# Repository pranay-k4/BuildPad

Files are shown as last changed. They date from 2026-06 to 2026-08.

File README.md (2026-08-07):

# BuildPad
BuildPad is customizable macro pad with OLED display, layers, media controls and more.

## Why BuildPad?
BuildPad is customizable open-source macropad for makers, coders, designers, and electronics builders and why I made this because building something yourself is way more fun than buying it and I love hardware.

## Features
- 6 programmable mechanical keys
- Rotary encoder
- OLED display
- RGB lighting
- Custom firmware
- Open-source hardware
- Bongo Cat animation

## CAD Render
Opera Snapshot_2026-07-03_222907_cad onshape com
Opera Snapshot_2026-07-03_222953_cad onshape com

## PCB Screenshots



## Hardware
- XIAO RP2040
- SSD1306 128×32 OLED
- MX Cherry Switches
- SK6812 MINI E Leds
- EC11 Rotary Encoder

## Build Your Own BuildPad

### 1. Order the PCB
Export the Gerber files from the PCB folder and order the board from your preferred PCB manufacturer.

### 2. Print the Case
Print the top and bottom case parts using the files in the case directory.

[CAD Source](https://cad.onshape.com/documents/56e50c354be83b1f527c4f36/w/ea902eb5d511072ea0b73db3/e/02ae305e326d8373da2c26ce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)

### 3. Gather Components
Use the BOM to source all required components.

### 4. Assemble the PCB
Solder:
1. Diodes
2. RGB LEDs
3. XIAO RP2040
4. OLED Display
5. Rotary Encoder
6. Mechanical Switches

### 5. Install Heat Set Inserts
Install M2 heat-set inserts into the top case.

### 6. Flash Firmware
Install QMK and compile:
```bash
qmk compile -kb buildpad -km default
```
Flash the generated firmware onto the XIAO RP2040.

### 7. Assemble the Case
Mount the PCB inside the case and secure everything using M2 screws.

## BOM
# Bill of Materials

| Item | Qty | Component | Specification | Price | Link |
|---|-----|---|---|---|---|
| 1 | 1 | Microcontroller | Seeed Studio XIAO RP2040 | ~$6-7 | https://robu.in/product/seeed-studio-xiao-rp2040-v1-0/ |
| 2 | 1 | OLED Display | 0.91in SSD1306 I2C OLED (128x32) | ~$2.5 | https://robu.in/product/0-91-inch-128x32-i2c-iic-serial-blue-oled-lcd-display-module/ |
| 3 | 1 | Rotary Encoder | EC11 Encoder with Push Switch | ~$0.6 | https://robu.in/product/hongyan-ec11h-7ce20p1zy20-rotary-encoder-with-push-button-switch-vertical-plug-in-5-pin/ |
| 4 | 1 | Mechanical Switches | Cherry MX Compatible Switches (Pack of 10) | ~$4 | https://meckeys.com/shop/accessories/keyboard-accessories/key-switches/cherry-mx-rgb-switch/ |
| 5 | 2 | Keycaps | MX Compatible Keycaps (Pack of 5) | ~$2 | https://meckeys.com/shop/accessories/keyboard-accessories/keycaps/blank/blank-dsa-keycaps-1u/ |
| 6 | 8 | RGB LEDs | SK6812MINI-E Reverse Mount RGB LEDs | ~$3 | https://www.lcsc.com/product-detail/C5149201.html |
| 7 | 6 | Diodes | 1N4148W SOD-123 | ~$0.5 | https://www.lcsc.com/product-detail/C81598.html |
| 8 | 1 | PCB | BuildPad v1 PCB | $4 + $8 shipping | JLCPCB |
| 9 | 1 | Case | BuildPad v1 3D Printed Case | - | - |
| 10 | 8 | Heat Set Inserts | M2 Brass Heat Set Inserts | ~$1.5 | https://robu.in/product/m2-x-4-mm-brass-insert/ |
| 11 | 4 | Screws | M2 Machine Screws 12mm Long | ~$0.5 | https://robu.in/product/easymech-m2-x-12mm-hex-allen-csk-high-tensile109-black-oxide-screw-dia-2mm-length-12mm/ |
| 12 | 4 | Screws | M2 Machine Screws 4mm Long | ~$0.5 | TBD |
| 13 | 1 | Encoder Knob | 6mm Shaft Encoder Knob | ~$1 | TBD |

## License
This project is licensed under the MIT License.

## Author
Pranay Kamle

BuildPad v1 • 2026

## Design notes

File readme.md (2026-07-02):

# buildpad

buildpad

*A short description of the keyboard/project*

* Keyboard Maintainer: [Pranay](https://https://github.com/pranay-k4)
* Hardware Supported: *The PCBs, controllers supported*
* Hardware Availability: *Links to where you can find this hardware*

Make example for this keyboard (after setting up your build environment):

    make buildpad:default

Flashing example for this keyboard:

    make buildpad:default:flash

See the [build environment setup](https://docs.qmk.fm/#/getting_started_build_tools) and the [make instructions](https://docs.qmk.fm/#/getting_started_make_guide) for more information. Brand new to QMK? Start with our [Complete Newbs Guide](https://docs.qmk.fm/#/newbs).

## Bootloader

Enter the bootloader in 3 ways:

* **Bootmagic reset**: Hold down the key at (0,0) in the matrix (usually the top left key or Escape) and plug in the keyboard
* **Physical reset button**: Briefly press the button on the back of the PCB - some may have pads you must short instead
* **Keycode in layout**: Press the key mapped to `QK_BOOT` if it is available

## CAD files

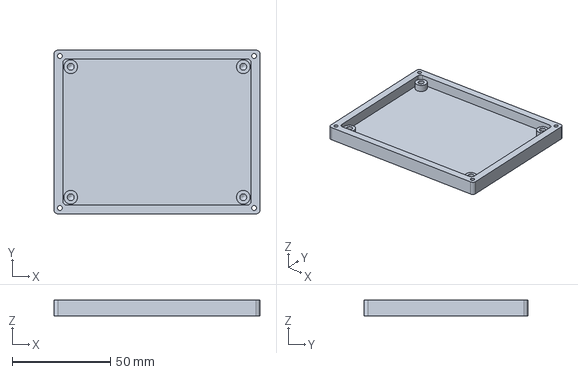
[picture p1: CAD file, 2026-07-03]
cad/Bottom part.step
105.0 x 83.5 x 8.00 mm

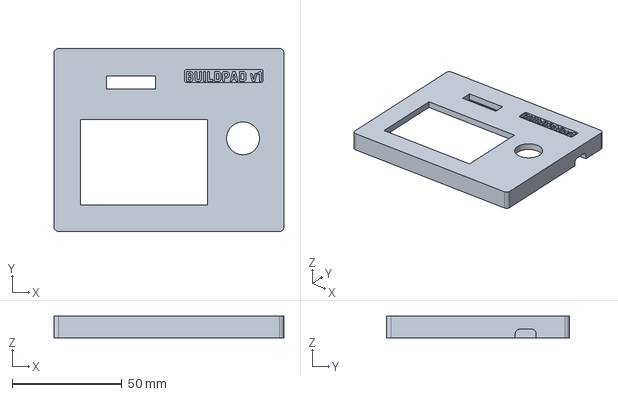
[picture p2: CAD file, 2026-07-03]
cad/Top part.step
105.0 x 83.5 x 10.0 mm

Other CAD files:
cad/Assembly.step
cad/Top part (1).stl
cad/Bottom part (1).stl
cad/Bottom part.stl
cad/Top part.stl

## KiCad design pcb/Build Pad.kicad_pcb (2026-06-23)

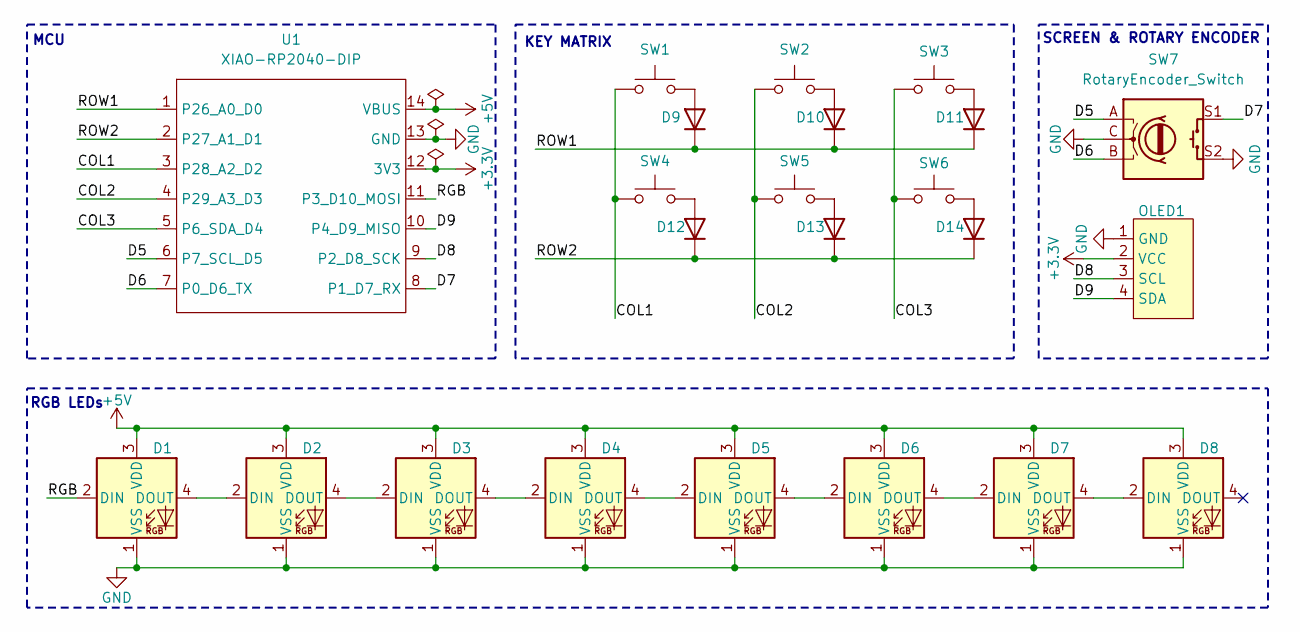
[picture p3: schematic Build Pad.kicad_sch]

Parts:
D1, D2, D3, D4, D5, D6, D7, D8: SK6812MINI-E; LED_SK6812MINI-E_3.2x2.8mm_P1.5mm_ReverseMount
D9, D10, D11, D12, D13, D14: 1N4148; D_SOD-123
OLED1: HS91L02W2C01; OLED-TH_L38.0-W12.0_HS91L02W2C01; MPN HS91L02W2C01; LCSC Part C5248081
SW1, SW2, SW3, SW4, SW5, SW6: SW_Push; SW_Cherry_MX_1.00u_PCB
SW7: RotaryEncoder_Switch; RotaryEncoder_Alps_EC11E-Switch_Vertical_H20mm_CircularMoun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
U1: XIAO-RP2040-DIP

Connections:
+3.3V: OLED1.2 (VCC), U1.12 (3V3)
+5V: D1.3 (VDD), D2.3 (VDD), D3.3 (VDD), D4.3 (VDD), D5.3 (VDD), D6.3 (VDD), D7.3 (VDD), D8.3 (VDD), U1.14 (VBUS)
/COL1: SW1.1, SW4.1, U1.3 (P28_A2_D2)
/COL2: SW2.1, SW5.1, U1.4 (P29_A3_D3)
/COL3: SW3.1, SW6.1, U1.5 (P6_SDA_D4)
/D5: SW7.A, U1.6 (P7_SCL_D5)
/D6: SW7.B, U1.7 (P0_D6_TX)
/D7: SW7.S1, U1.8 (P1_D7_RX)
/D8: OLED1.3 (SCL), U1.9 (P2_D8_SCK)
/D9: OLED1.4 (SDA), U1.10 (P4_D9_MISO)
/RGB: D1.2 (DIN), U1.11 (P3_D10_MOSI)
/ROW1: D9.1 (K), D10.1 (K), D11.1 (K), U1.1 (P26_A0_D0)
/ROW2: D12.1 (K), D13.1 (K), D14.1 (K), U1.2 (P27_A1_D1)
GND: D1.1 (VSS), D2.1 (VSS), D3.1 (VSS), D4.1 (VSS), D5.1 (VSS), D6.1 (VSS), D7.1 (VSS), D8.1 (VSS), OLED1.1 (GND), SW7.C, SW7.S2, U1.13 (GND)
unnamed: D1.4 (DOUT), D2.2 (DIN)
unnamed: D2.4 (DOUT), D3.2 (DIN)
unnamed: D3.4 (DOUT), D4.2 (DIN)
unnamed: D4.4 (DOUT), D5.2 (DIN)
unnamed: D5.4 (DOUT), D6.2 (DIN)
unnamed: D6.4 (DOUT), D7.2 (DIN)
unnamed: D7.4 (DOUT), D8.2 (DIN)
unnamed: D9.2 (A), SW1.2
unnamed: D10.2 (A), SW2.2
unnamed: D11.2 (A), SW3.2
unnamed: D12.2 (A), SW4.2
unnamed: D13.2 (A), SW5.2
unnamed: D14.2 (A), SW6.2

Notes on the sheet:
MCU
RGB LEDs
SCREEN & ROTARY ENCODER
KEY MATRIX

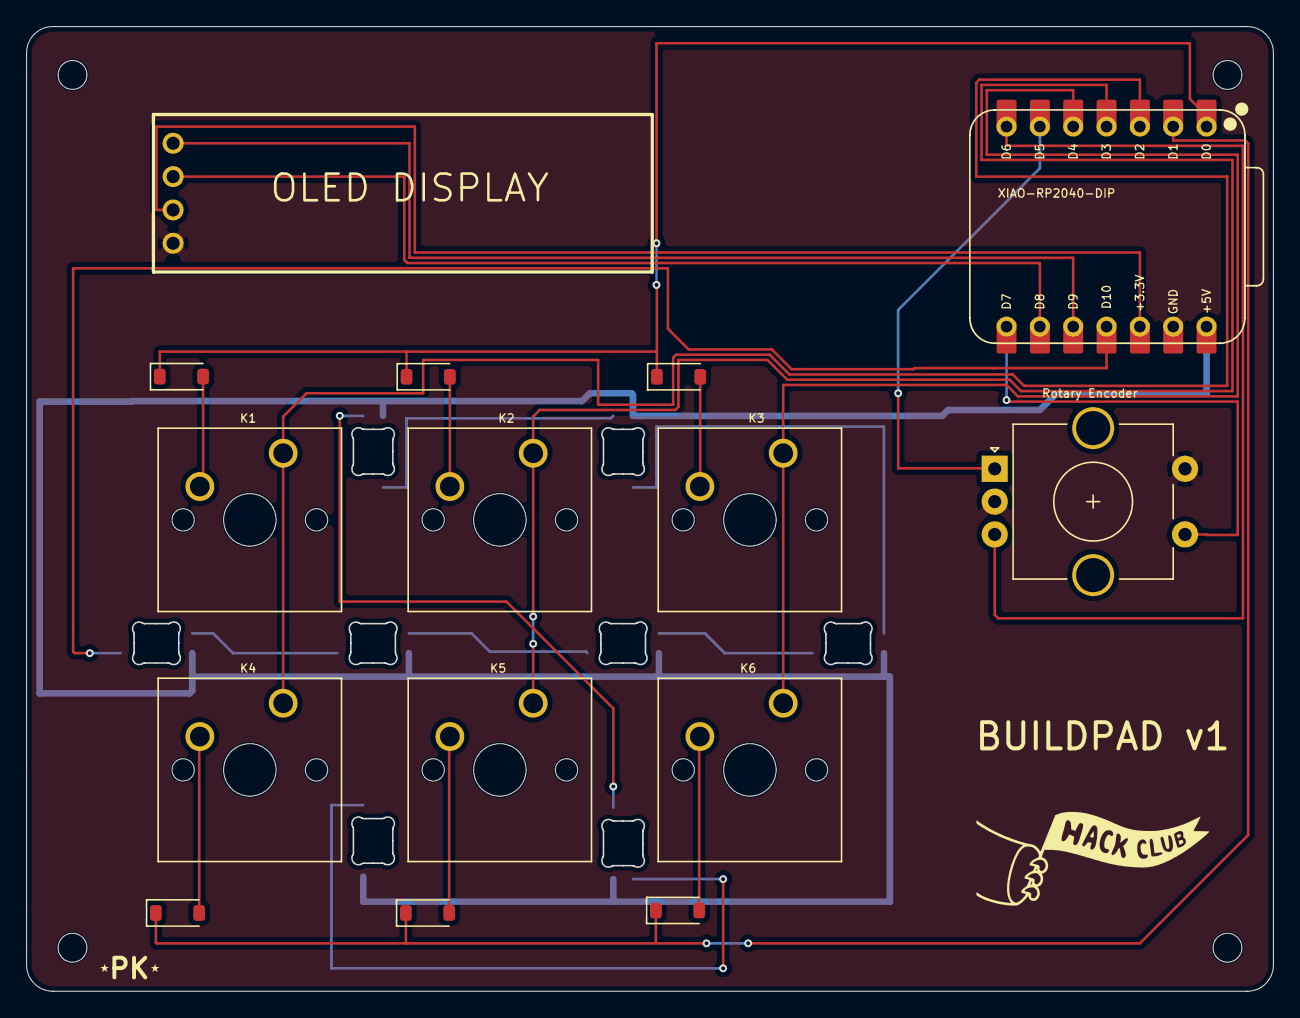
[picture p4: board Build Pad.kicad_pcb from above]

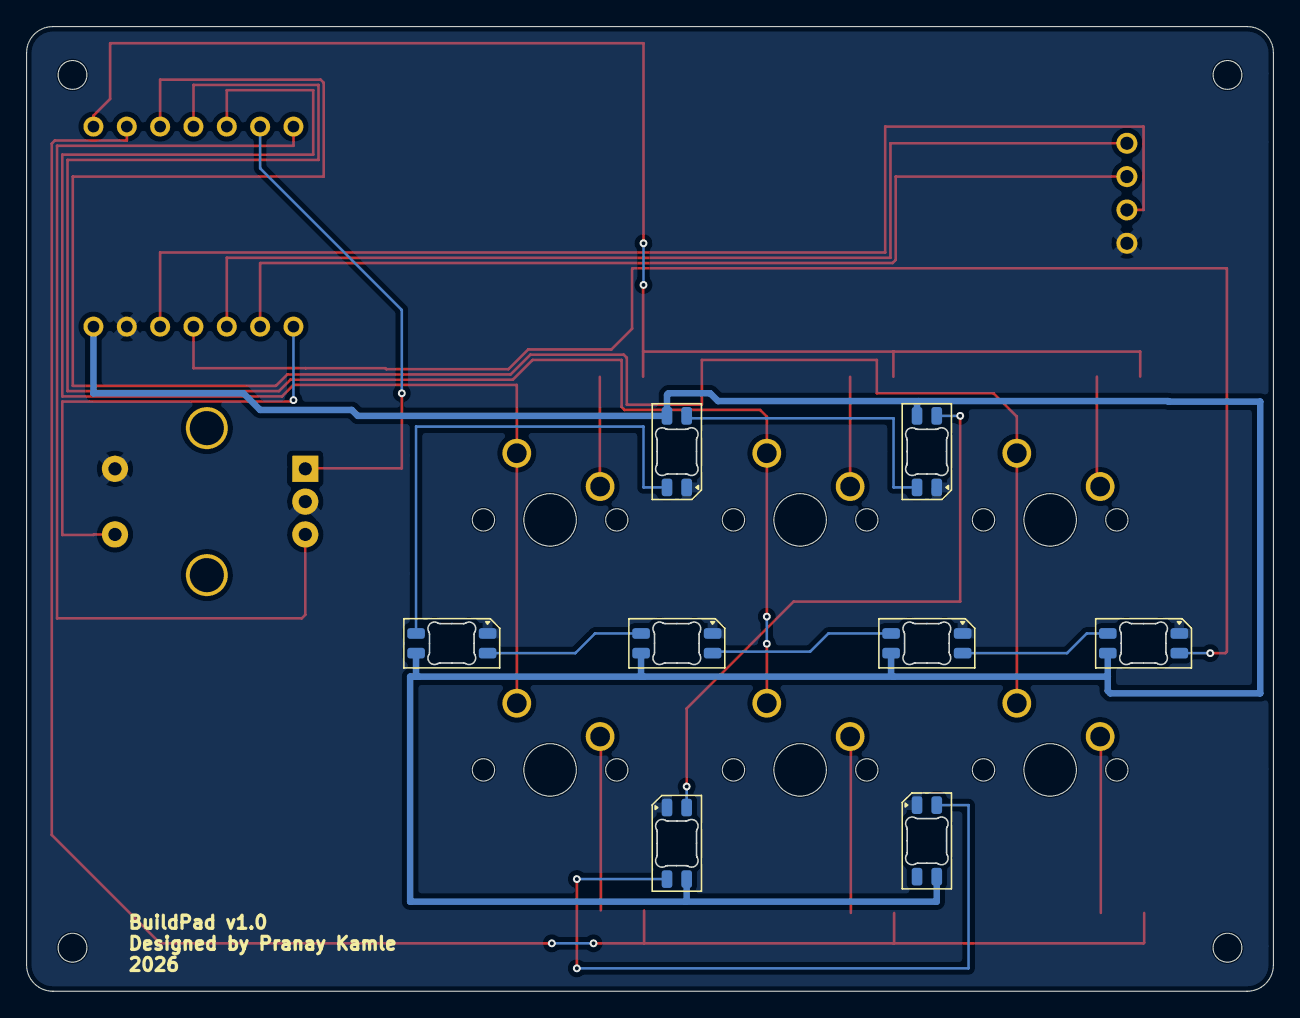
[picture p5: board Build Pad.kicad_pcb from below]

Board: 2 copper layers, 95.0 x 73.5 mm, 23 parts (8 on the bottom side), 27 nets.

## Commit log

2026-06-14 Rename Build Pad.kicad_sch to PCB/Build Pad.kicad_sch
    [Build Pad.kicad_sch]
2026-06-17 Rename BuildPad v1.zip to PCB/BuildPad v1.zip
2026-06-23 Rename BuildPad v1 Final.zip to BuildPad v1 (Gerbers).zip
2026-07-02 Rename Top Part.step to CAD/Top Part.ste
2026-07-02 Rename Build Pad.kicad_pcb to Build Pad.kicad_pcb
    [Build Pad.kicad_pcb]
2026-07-02 Rename Build Pad.kicad_sch to Build Pad.kicad_sch
    [Build Pad.kicad_sch]
2026-07-02 Rename BuildPad v1 (Gerbers).zip to BuildPad v1 (Gerbers).zip
2026-07-02 Rename Bottom Part.step to Bottom Part.step
    [Bottom Part.step]
2026-07-02 Rename Top Part.ste to Top Part.step
    [Top Part.step]
2026-07-03 Rename Bottom part (1).step to Bottom part.step
    [Bottom part.step]
2026-07-03 Rename Top part (1).step to Top part.step
    [Top part.step]
2026-07-03 Rename Top part (2).step to Top part.step
    [Top part.step]
2026-07-03 Rename Top part (1).stl to Top part.stl
    [Top part.stl]
2026-07-03 Rename Bottom part (2).step to Bottom part.step
    [Bottom part.step]
2026-07-03 Rename Bottom part (1).stl to Bottom part.stl
    [Bottom part.stl]
2026-08-08 Rename Assembly (2).step to Assembly.step
    [Assembly.step]
